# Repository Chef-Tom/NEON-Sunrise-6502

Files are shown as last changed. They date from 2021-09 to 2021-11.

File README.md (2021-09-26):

# NEON-Sunrise-6502
The 6502 based Prototypes

This started in early 2021 as a work from hom distraction and quickly grew into an obsession.
This repository is to work in conjuction with the blog at http://realcheftom.com/6502
and my YouTube documentation of the project at https://www.youtube.com/watch?v=W5MUhNn74IM&list=PLEm9BpY3woKBx9LlBmEiw2NBphkDs04n8

Comments and updates welcome!

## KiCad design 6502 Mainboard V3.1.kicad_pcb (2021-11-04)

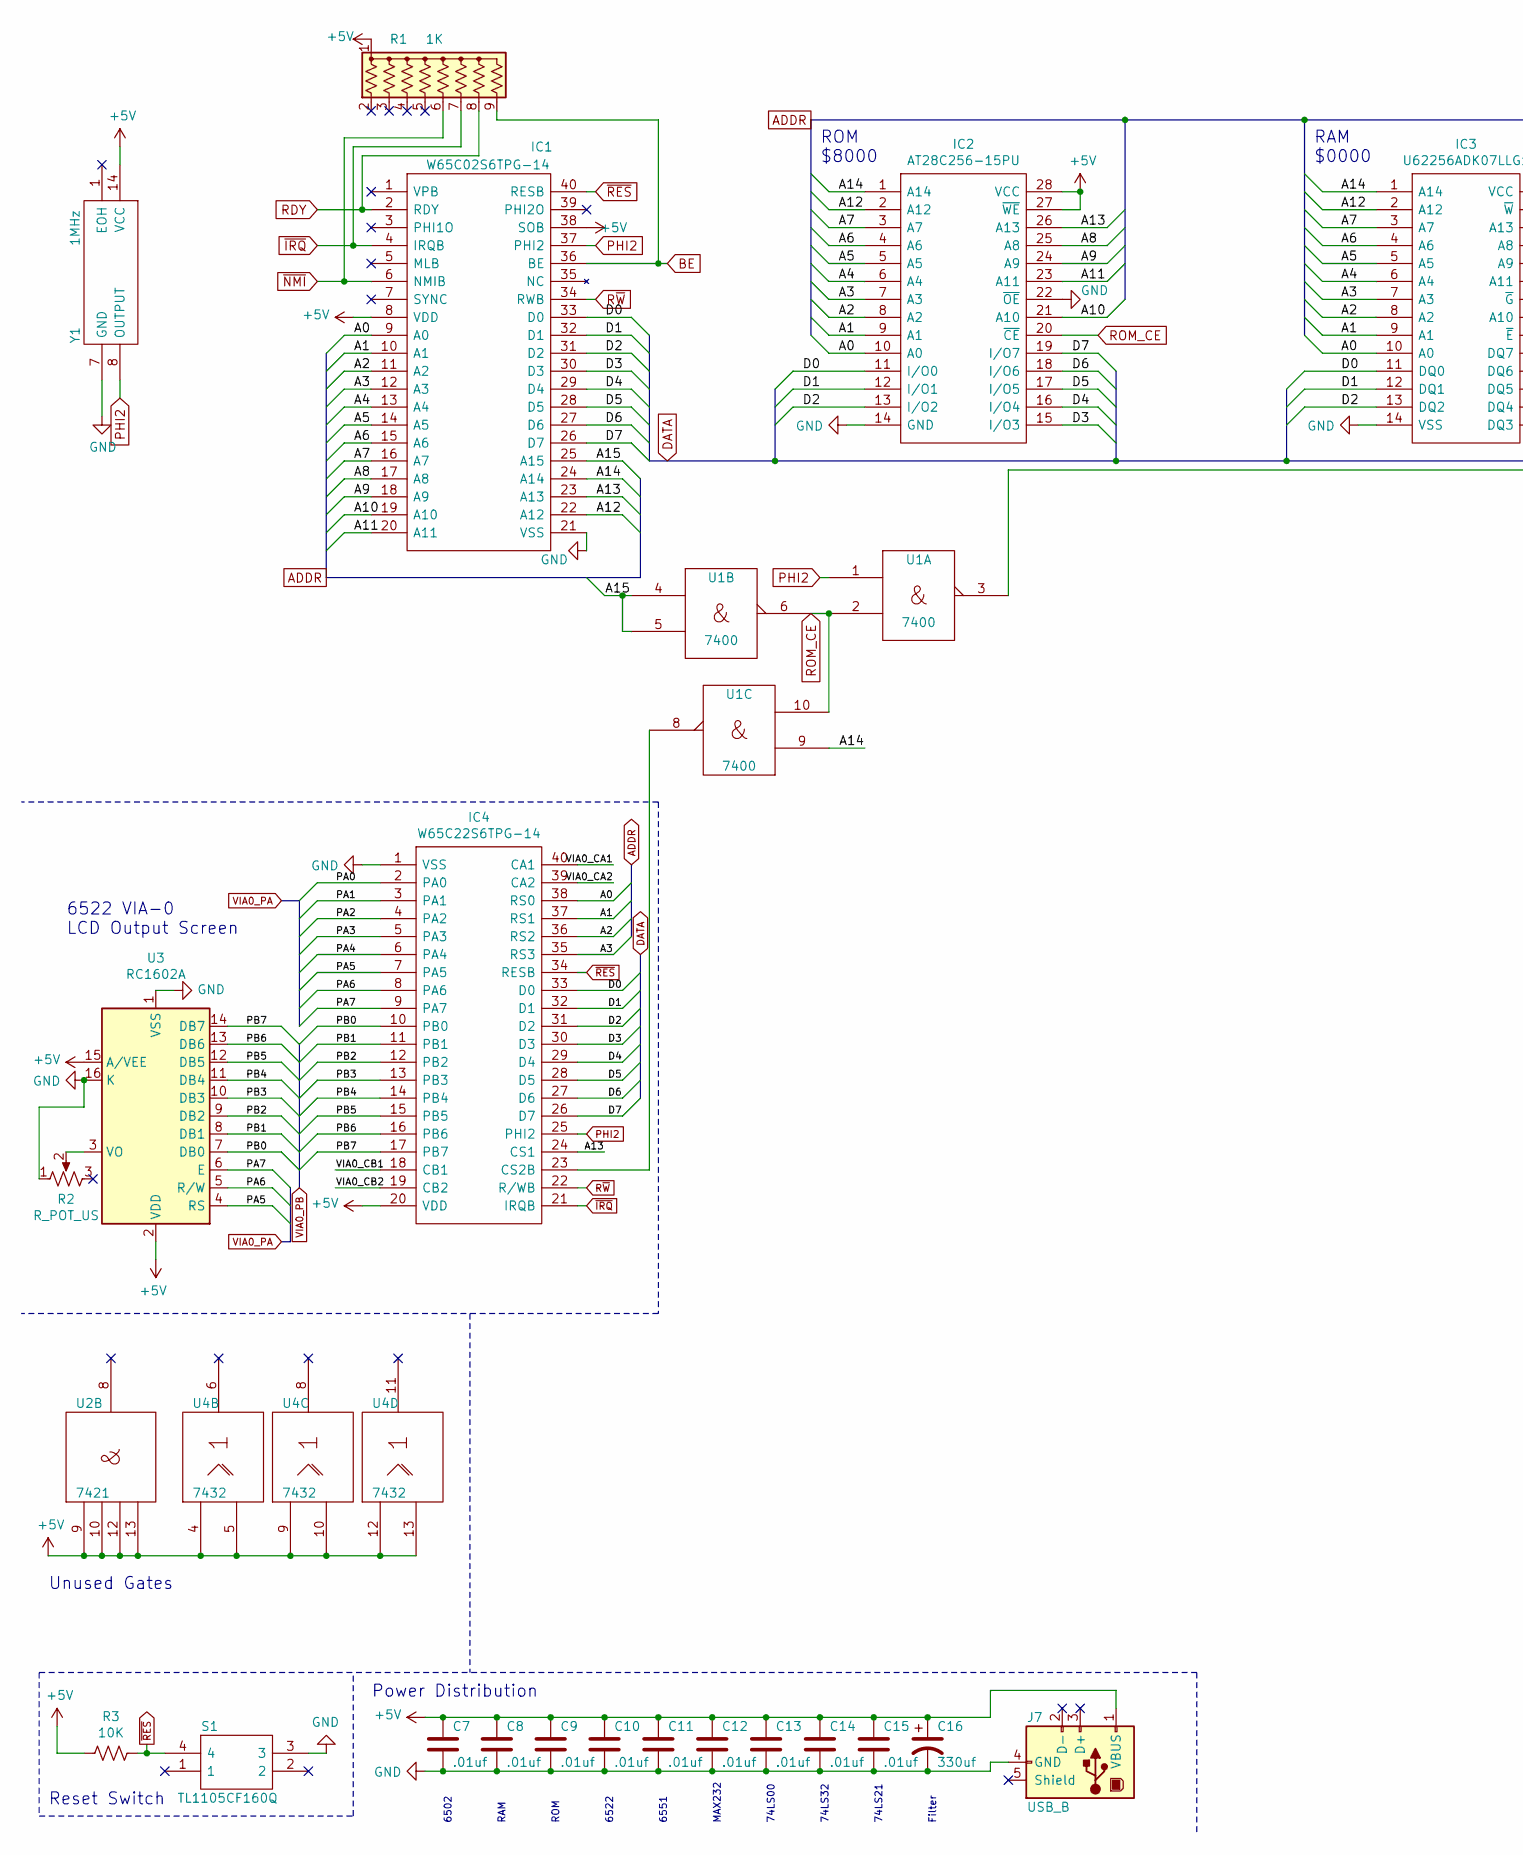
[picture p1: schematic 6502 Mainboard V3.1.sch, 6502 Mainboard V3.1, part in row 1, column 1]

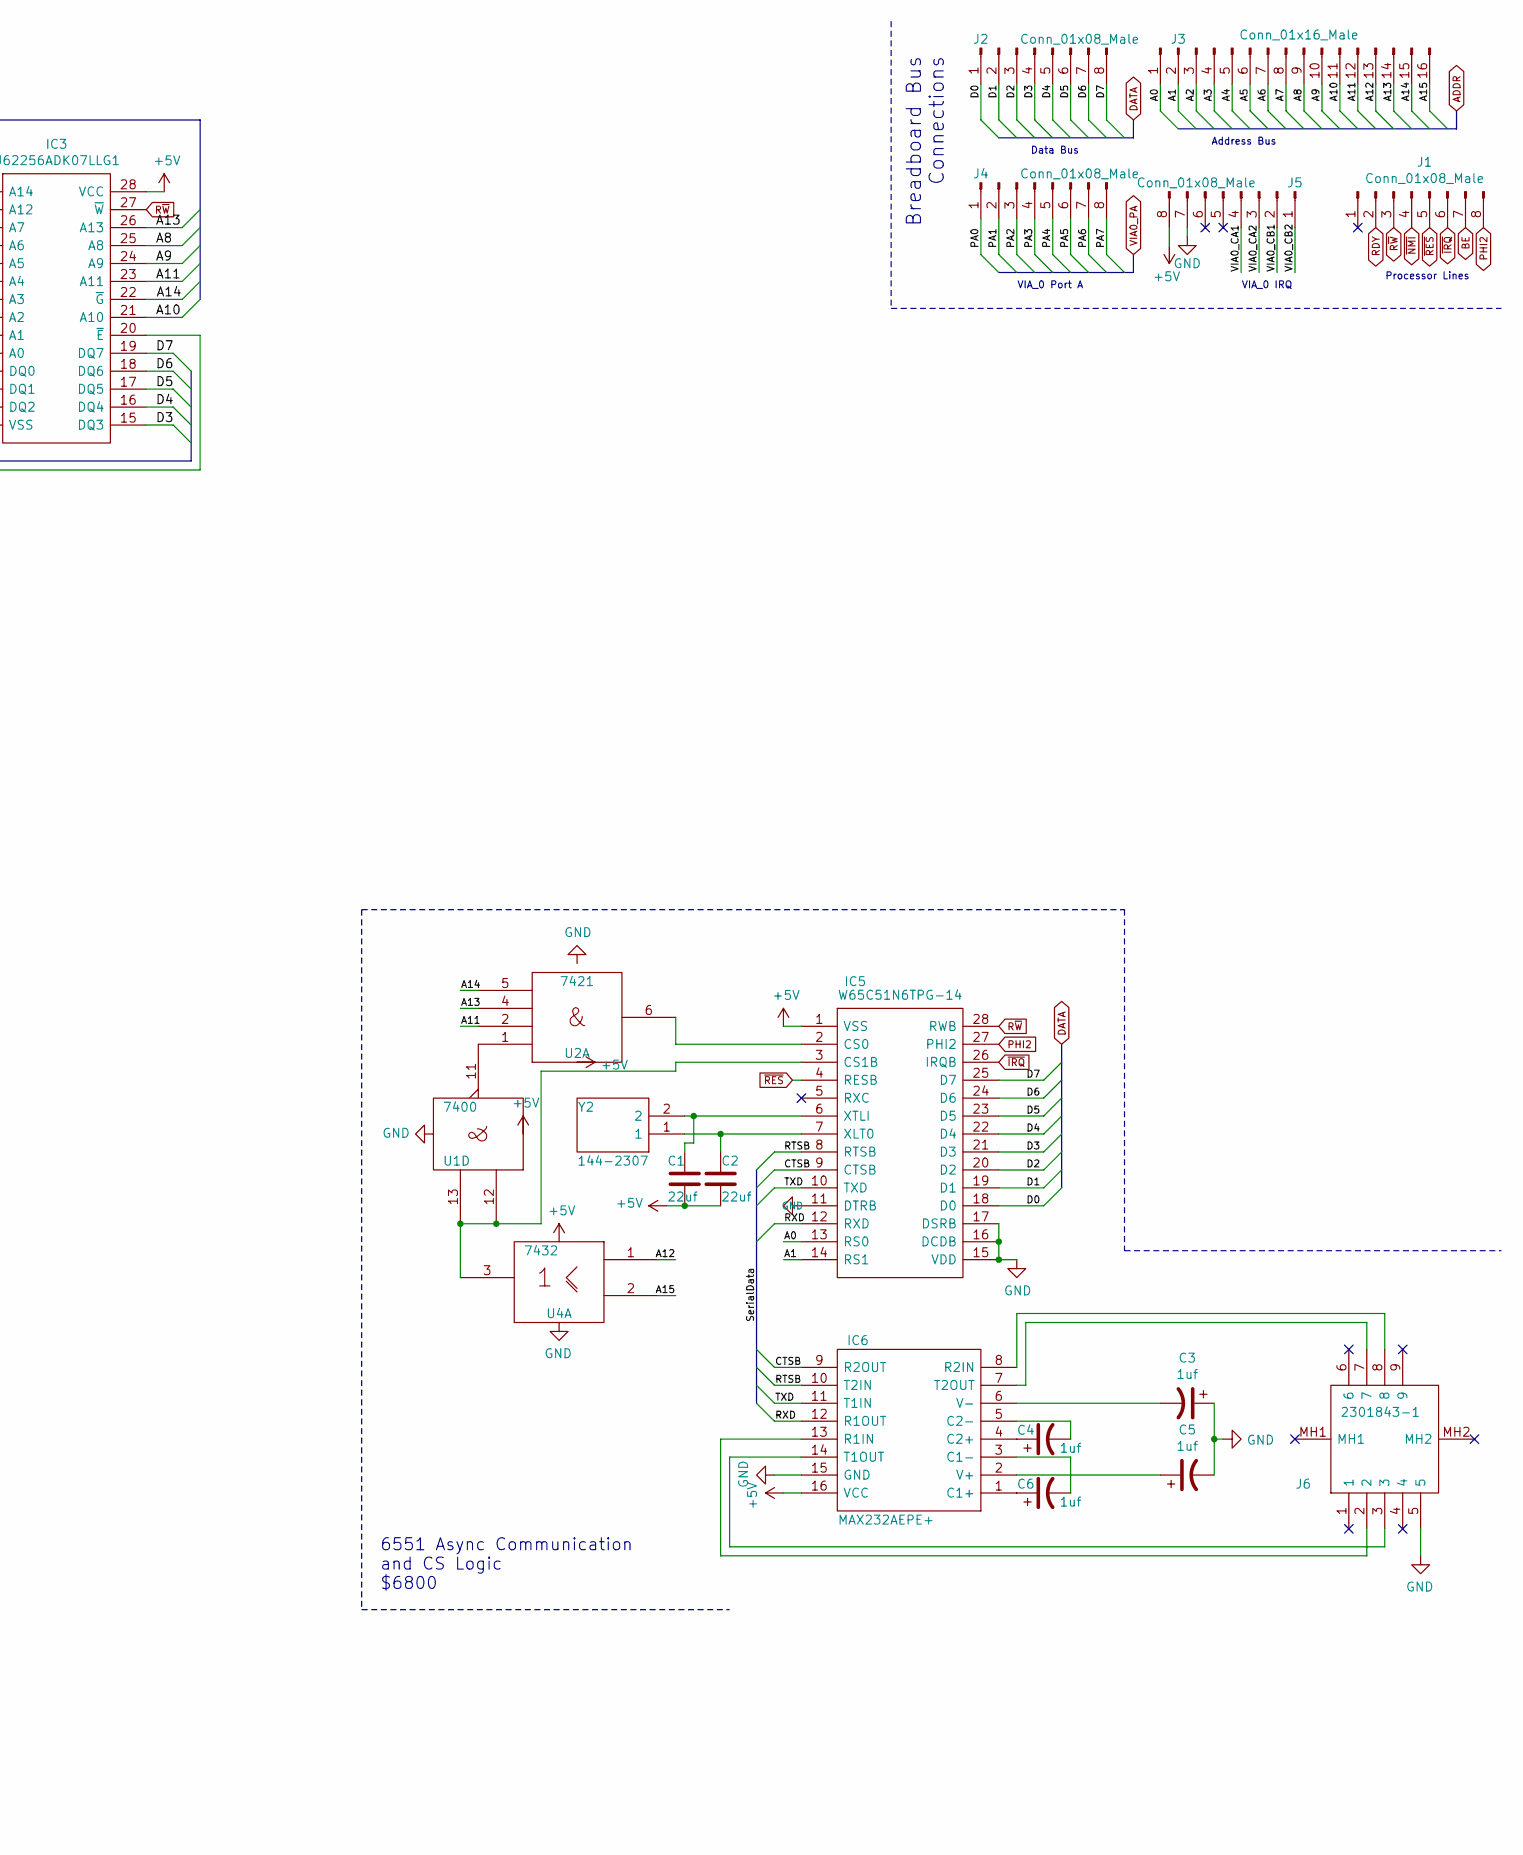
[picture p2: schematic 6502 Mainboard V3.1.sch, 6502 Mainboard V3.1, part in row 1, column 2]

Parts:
C1, C2: 22uf; C_Disc_D3.4mm_W2.1mm_P2.50mm
C3, C4, C5, C6: 1uf; CP_Radial_D5.0mm_P2.50mm
C7, C8, C9, C10, C11, C12, C13, C14, C15: .01uf; C_Disc_D4.3mm_W1.9mm_P5.00mm
C16: 330uf; CP_Radial_D6.3mm_P2.50mm
IC1: W65C02S6TPG-14; DIP-40_W15.24mm_LongPads; Manufacturer_Part_Number W65C02S6TPG-14; Mouser Part Number 955-W65C02S6TPG-14
IC2: AT28C256-15PU; DIP-28_W15.24mm_LongPads; Manufacturer_Part_Number AT28C256-15PU; Mouser Part Number 556-AT28C25615PU
IC3: U62256ADK07LLG1; DIP-28_W15.24mm_LongPads; Manufacturer_Part_Number U62256ADK07LLG1; Mouser Part Number 913-U62256ADK07LLG1
IC4: W65C22S6TPG-14; DIP-40_W15.24mm_LongPads; Manufacturer_Part_Number W65C22S6TPG-14; Mouser Part Number 955-W65C22S6TPG-14
IC5: W65C51N6TPG-14; DIP-28_W15.24mm_LongPads; Manufacturer_Part_Number W65C51N6TPG-14; Mouser Part Number 955-W65C51N6TPG-14
IC6: MAX232AEPE+; DIP-16_W7.62mm_LongPads; Manufacturer_Part_Number MAX232AEPE+; Mouser Part Number 700-MAX232AEPE
J1, J2, J4, J5: Conn_01x08_Male; PinHeader_1x08_P2.54mm_Vertical
J3: Conn_01x16_Male; PinHeader_1x16_P2.54mm_Vertical
J6: 2301843-1; 23018431; Manufacturer_Part_Number 2301843-1; Mouser Part Number 571-2301843-1
J7: USB_B; USB_B_Lumberg_2411_02_Horizontal
R1: 1K; R_Array_SIP9
R2: R_POT_US; Potentiometer_Vishay_T73YP_Vertical
R3: 10K; R_Axial_DIN0411_L9.9mm_D3.6mm_P15.24mm_Horizontal
S1: TL1105CF160Q; Manufacturer_Part_Number TL1105CF160Q; Mouser Part Number 612-TL1105C
U1: 7400; DIP-14_W7.62mm_LongPads
U2: 7421; DIP-14_W7.62mm_LongPads
U3: RC1602A; WC1602A
U4: 7432; DIP-14_W7.62mm_LongPads
Y1: 1MHz; MXO45T2C1M0000; Manufacturer_Part_Number MXO45T-2C-1M0000; Mouser Part Number 774-MXO45T-2C-1M0000
Y2: 144-2307; Crystal_HC52-6mm_Vertical; Manufacturer_Part_Number 144-2307

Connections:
+5V: C1.2, C2.2, C7.1, C8.1, C9.1, C10.1, C11.1, C12.1, C13.1, C14.1, C15.1, C16.1, IC1.8 (VDD), IC1.38 (SOB), IC2.27 (~WE), IC2.28 (VCC), IC3.28 (VCC), IC4.20 (VDD), IC5.1 (VSS), IC6.16 (VCC), J5.8, J7.1 (VBUS), R1.1 (common), R3.2, U1.14 (Vcc), U2.9, U2.10, U2.12, U2.13, U2.14 (Vcc), U3.2 (VDD), U3.15 (A/VEE), U4.4, U4.5, U4.9, U4.10, U4.12, U4.13, U4.14 (Vcc), Y1.14 (VCC)
/A0: IC1.9 (A0), IC2.10 (A0), IC3.10 (A0), IC4.38 (RS0), IC5.13 (RS0), J3.1
/A1: IC1.10 (A1), IC2.9 (A1), IC3.9 (A1), IC4.37 (RS1), IC5.14 (RS1), J3.2
/A2: IC1.11 (A2), IC2.8 (A2), IC3.8 (A2), IC4.36 (RS2), J3.3
/A3: IC1.12 (A3), IC2.7 (A3), IC3.7 (A3), IC4.35 (RS3), J3.4
/A4: IC1.13 (A4), IC2.6 (A4), IC3.6 (A4), J3.5
/A5: IC1.14 (A5), IC2.5 (A5), IC3.5 (A5), J3.6
/A6: IC1.15 (A6), IC2.4 (A6), IC3.4 (A6), J3.7
/A7: IC1.16 (A7), IC2.3 (A7), IC3.3 (A7), J3.8
/A8: IC1.17 (A8), IC2.25 (A8), IC3.25 (A8), J3.9
/A9: IC1.18 (A9), IC2.24 (A9), IC3.24 (A9), J3.10
/A10: IC1.19 (A10), IC2.21 (A10), IC3.21 (A10), J3.11
/A11: IC1.20 (A11), IC2.23 (A11), IC3.23 (A11), J3.12, U2.2
/A12: IC1.22 (A12), IC2.2 (A12), IC3.2 (A12), J3.13, U4.1
/A13: IC1.23 (A13), IC2.26 (A13), IC3.26 (A13), IC4.24 (CS1), J3.14, U2.4
/A14: IC1.24 (A14), IC2.1 (A14), IC3.1 (A14), IC3.22 (~G), J3.15, U1.9, U2.5
/A15: IC1.25 (A15), J3.16, U1.4, U1.5, U4.2
/CTSB: IC5.9 (CTSB), IC6.9 (R2OUT)
/D0: IC1.33 (D0), IC2.11 (I/O0), IC3.11 (DQ0), IC4.33 (D0), IC5.18 (D0), J2.1
/D1: IC1.32 (D1), IC2.12 (I/O1), IC3.12 (DQ1), IC4.32 (D1), IC5.19 (D1), J2.2
/D2: IC1.31 (D2), IC2.13 (I/O2), IC3.13 (DQ2), IC4.31 (D2), IC5.20 (D2), J2.3
/D3: IC1.30 (D3), IC2.15 (I/O3), IC3.15 (DQ3), IC4.30 (D3), IC5.21 (D3), J2.4
/D4: IC1.29 (D4), IC2.16 (I/O4), IC3.16 (DQ4), IC4.29 (D4), IC5.22 (D4), J2.5
/D5: IC1.28 (D5), IC2.17 (I/O5), IC3.17 (DQ5), IC4.28 (D5), IC5.23 (D5), J2.6
/D6: IC1.27 (D6), IC2.18 (I/O6), IC3.18 (DQ6), IC4.27 (D6), IC5.24 (D6), J2.7
/D7: IC1.26 (D7), IC2.19 (I/O7), IC3.19 (DQ7), IC4.26 (D7), IC5.25 (D7), J2.8
/PA0: IC4.2 (PA0), J4.1
/PA1: IC4.3 (PA1), J4.2
/PA2: IC4.4 (PA2), J4.3
/PA3: IC4.5 (PA3), J4.4
/PA4: IC4.6 (PA4), J4.5
/PA5: IC4.7 (PA5), J4.6, U3.4 (RS)
/PA6: IC4.8 (PA6), J4.7, U3.5 (R/W)
/PA7: IC4.9 (PA7), J4.8, U3.6 (E)
/PB0: IC4.10 (PB0), U3.7 (DB0)
/PB1: IC4.11 (PB1), U3.8 (DB1)
/PB2: IC4.12 (PB2), U3.9 (DB2)
/PB3: IC4.13 (PB3), U3.10 (DB3)
/PB4: IC4.14 (PB4), U3.11 (DB4)
/PB5: IC4.15 (PB5), U3.12 (DB5)
/PB6: IC4.16 (PB6), U3.13 (DB6)
/PB7: IC4.17 (PB7), U3.14 (DB7)
/RTSB: IC5.8 (RTSB), IC6.10 (T2IN)
/RXD: IC5.12 (RXD), IC6.12 (R1OUT)
/TXD: IC5.10 (TXD), IC6.11 (T1IN)
/VIA0_CA1: IC4.40 (CA1), J5.4
/VIA0_CA2: IC4.39 (CA2), J5.3
/VIA0_CB1: IC4.18 (CB1), J5.2
/VIA0_CB2: IC4.19 (CB2), J5.1
BE: IC1.36 (BE), J1.7, R1.9 (R8)
GND: C3.1, C5.2, C7.2, C8.2, C9.2, C10.2, C11.2, C12.2, C13.2, C14.2, C15.2, C16.2, IC1.21 (VSS), IC2.14 (GND), IC2.22 (~OE), IC3.14 (VSS), IC4.1 (VSS), IC5.11 (DTRB), IC5.15 (VDD), IC5.16 (DCDB), IC5.17 (DSRB), IC6.15 (GND), J5.7, J6.5, J7.4 (GND), R2.1, S1.3, U1.7 (GND), U2.7 (Gnd), U3.1 (VSS), U3.16 (K), U4.7 (Gnd), Y1.7 (GND)
unnamed: C1.1, IC5.6 (XTLI), Y2.2
unnamed: C2.1, IC5.7 (XLT0), Y2.1
unnamed: C3.2, IC6.6 (V-)
unnamed: C4.1, IC6.4 (C2+)
unnamed: C4.2, IC6.5 (C2-)
unnamed: C5.1, IC6.2 (V+)
unnamed: C6.1, IC6.1 (C1+)
unnamed: C6.2, IC6.3 (C1-)
unnamed: IC3.20 (~E), U1.3
unnamed: IC4.23 (CS2B), U1.8
unnamed: IC5.2 (CS0), U2.6
unnamed: IC5.3 (CS1B), U1.12, U1.13, U4.3
unnamed: IC6.7 (T2OUT), J6.7
unnamed: IC6.8 (R2IN), J6.8
unnamed: IC6.13 (R1IN), J6.2
unnamed: IC6.14 (T1OUT), J6.3
unnamed: R2.2, U3.3 (VO)
unnamed: U1.11, U2.1
PHI2: IC1.37 (PHI2), IC4.25 (PHI2), IC5.27 (PHI2), J1.8, U1.1, Y1.8 (OUTPUT)
RDY: IC1.2 (RDY), J1.2, R1.8 (R7)
ROM_CE: IC2.20 (~CE), U1.2, U1.6, U1.10
R~W: IC1.34 (RWB), IC3.27 (~W), IC4.22 (R/WB), IC5.28 (RWB), J1.3
~IRQ: IC1.4 (IRQB), IC4.21 (IRQB), IC5.26 (IRQB), J1.6, R1.7 (R6)
~NMI: IC1.6 (NMIB), J1.4, R1.6 (R5)
~RES: IC1.40 (RESB), IC4.34 (RESB), IC5.4 (RESB), J1.5, R3.1, S1.4

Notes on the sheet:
Reset Switch
6551 Async Communication and CS Logic $6800
ROM $8000
RAM $0000
6522 VIA-0 LCD Output Screen
6502
RAM
ROM
6522
6551
MAX232
74LS00
74LS32
74LS21
Filter
Power Distribution
Unused Gates
VIA_0 IRQ
VIA_0 Port A
Processor Lines
Address Bus
Data Bus
Breadboard Bus Connections

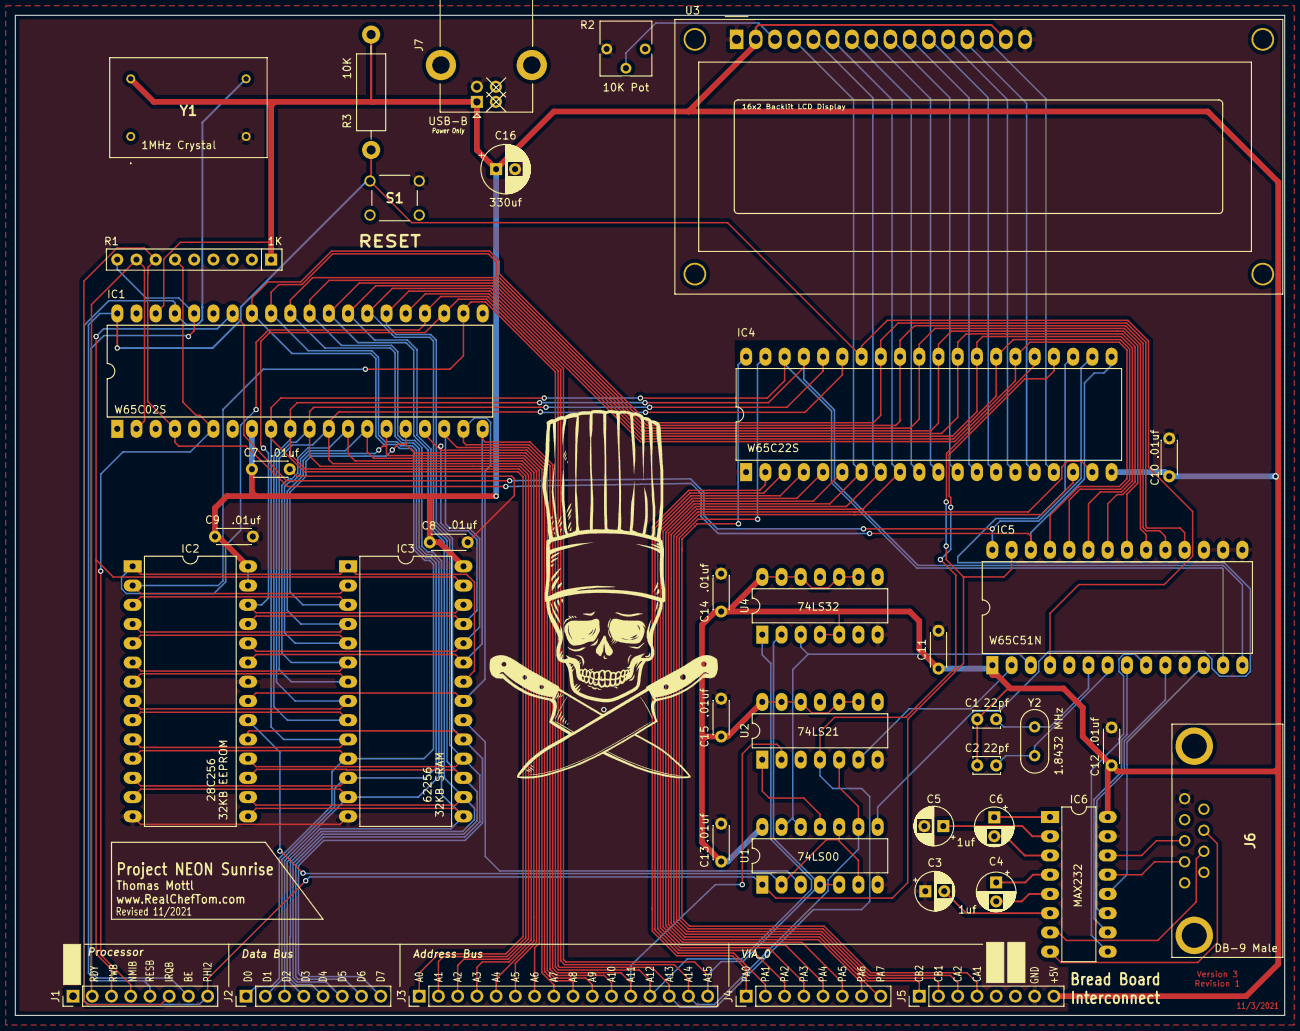
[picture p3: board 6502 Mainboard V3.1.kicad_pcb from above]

Board: 2 copper layers, 167.6 x 132.1 mm, 39 parts (0 on the bottom side), 76 nets.

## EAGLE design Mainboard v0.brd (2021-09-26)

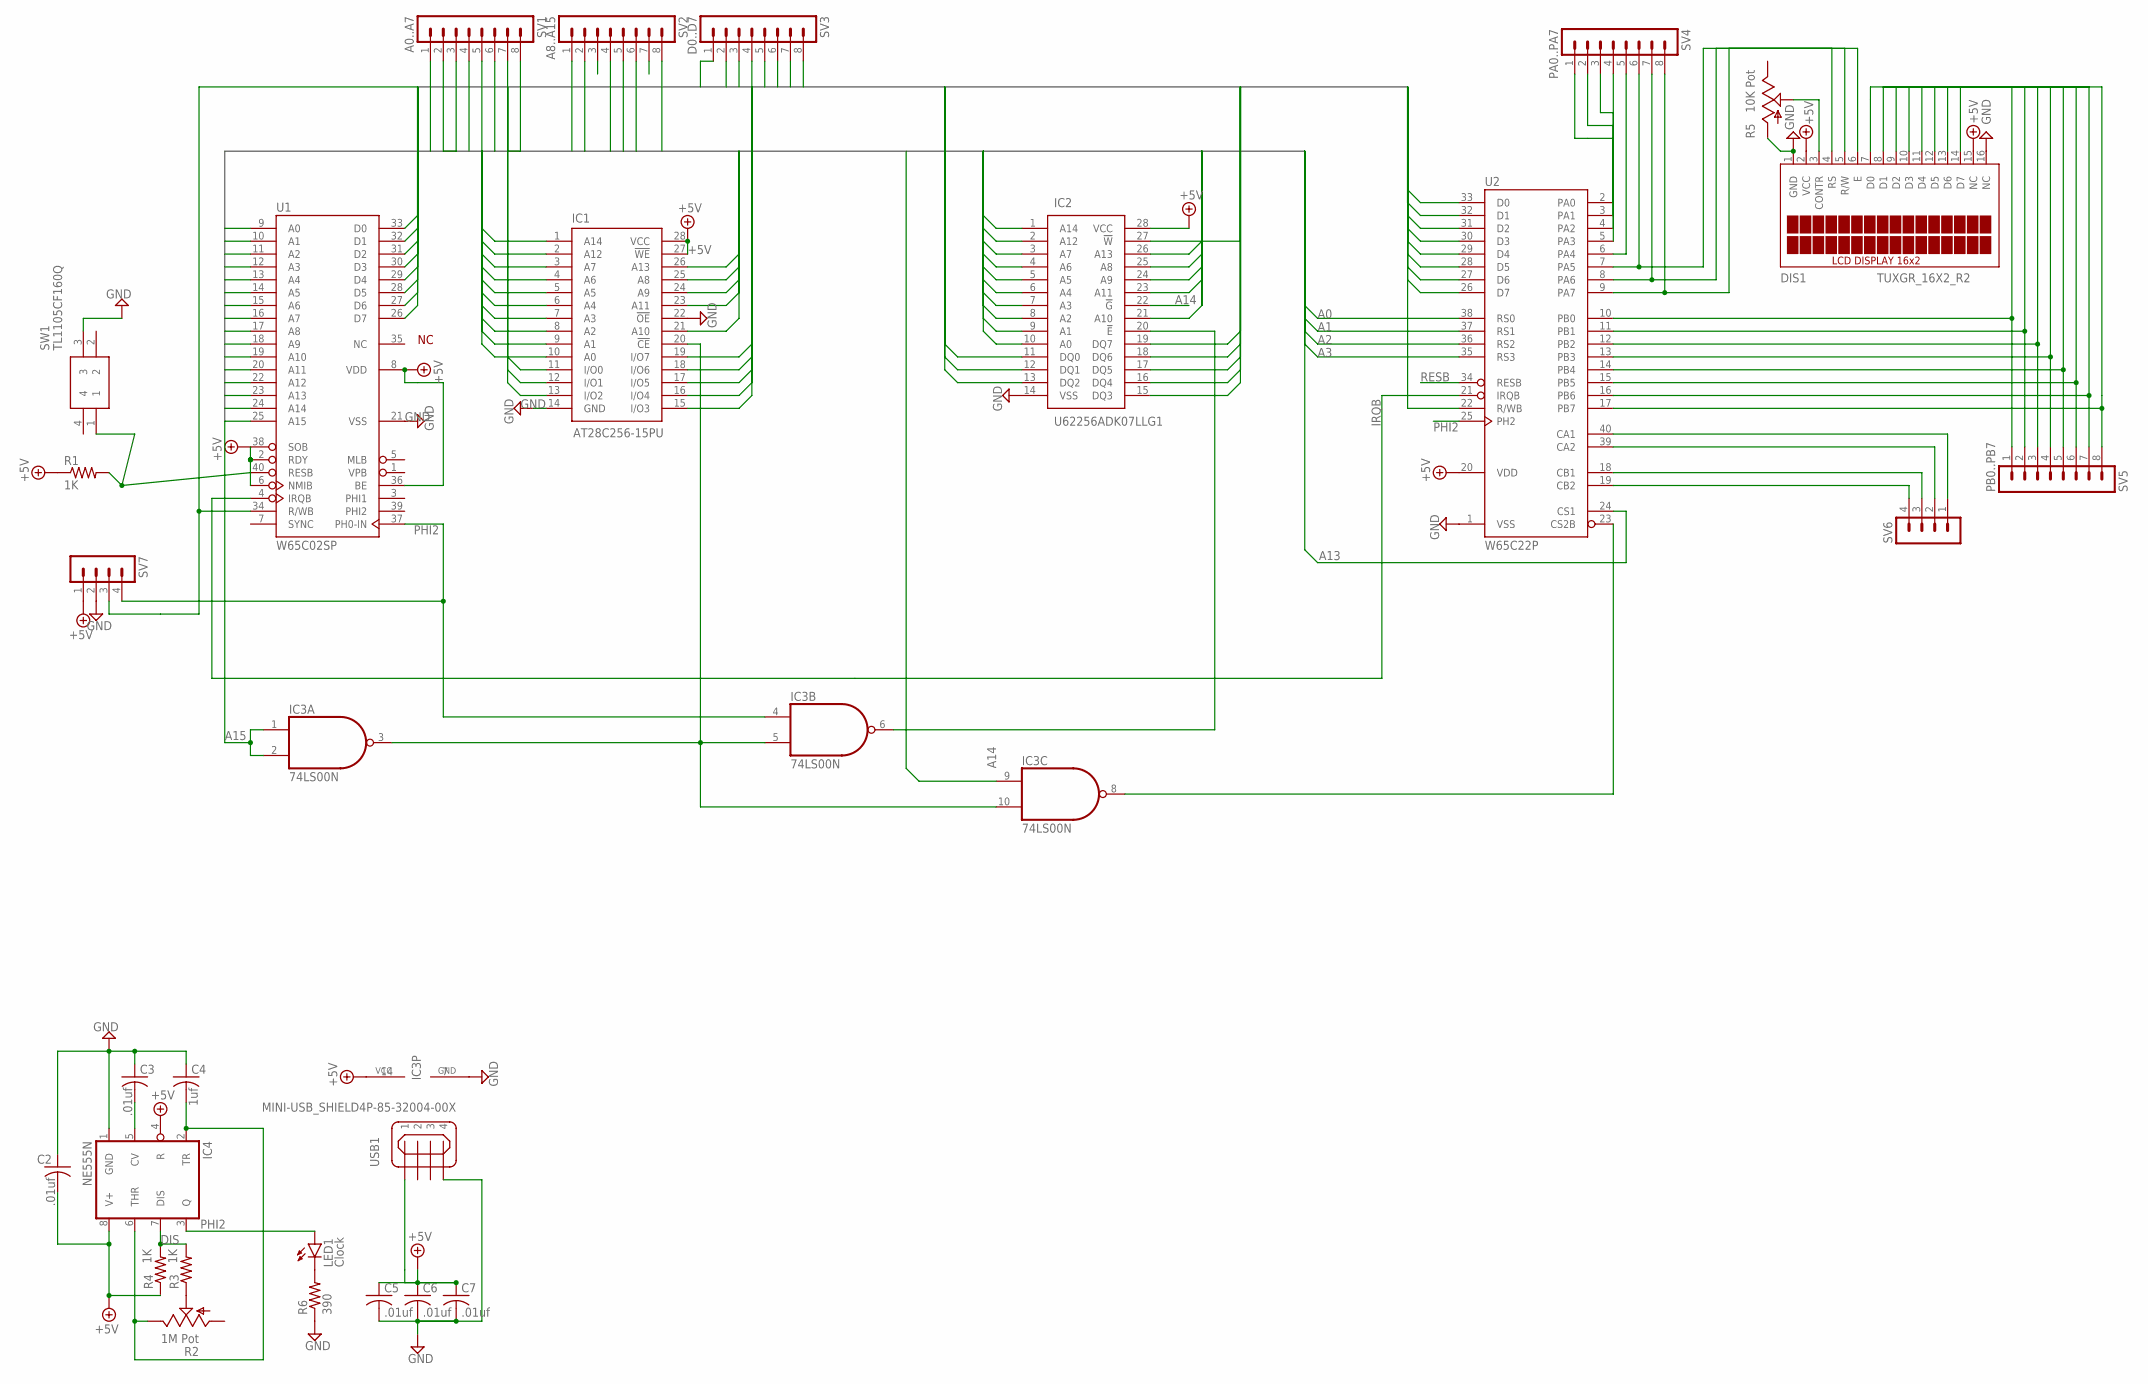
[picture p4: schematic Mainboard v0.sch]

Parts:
C2, C3, C5, C6, C7: .01uf; C075-032X103
C4: 1uf; C075-032X103
DIS1: TUXGR_16X2_R2
IC1: AT28C256-15PU; DIP1556W56P254L3702H483Q28N
IC2: U62256ADK07LLG1; DIP1524W59P254L3710H510Q28N
IC3: 74LS00N; DIL14
IC4: NE555N; DIL08
LED1: Clock; LED5MM
R1, R3, R4: 1K; 0204/7
R2: 1M Pot; B25U
R5: 10K Pot; B25U
R6: 390; 0204/7
SV1: A0..A7; MA08-1
SV2: A8..A15; MA08-1
SV3: D0..D7; MA08-1
SV4: PA0..PA7; MA08-1
SV5: PB0..PB7; MA08-1
SV6, SV7: MA04-1
SW1: TL1105CF160Q
U1: W65C02SP; DIP-40
U2: W65C22P; DIP-40
USB1: MINI-USB_SHIELD4P-85-32004-00X; 85-32004-00X

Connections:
+5V: C2.2, C5.1, C6.1, C7.1, DIS1.2 (VCC), DIS1.15 (NC), IC1.27 (!WE), IC1.28 (VCC), IC2.28 (VCC), IC3.14 (VCC), IC4.4 (R), IC4.8 (V+), R1.1, R4.1, SV7.1, U1.2 (RDY), U1.6 (NMIB), U1.8 (VDD), U1.36 (BE), U1.38 (SOB), U2.20 (VDD), USB1.1
A0: IC1.10 (A0), IC2.10 (A0), SV1.1, U1.9 (A0), U2.38 (RS0)
A1: IC1.9 (A1), IC2.9 (A1), SV1.2, U1.10 (A1), U2.37 (RS1)
A2: IC1.8 (A2), IC2.8 (A2), SV1.3, U1.11 (A2), U2.36 (RS2)
A3: IC1.7 (A3), IC2.7 (A3), SV1.4, U1.12 (A3), U2.35 (RS3)
A4: IC1.6 (A4), IC2.6 (A4), SV1.5, U1.13 (A4)
A5: IC1.5 (A5), IC2.5 (A5), SV1.6, U1.14 (A5)
A6: IC1.4 (A6), IC2.4 (A6), SV1.7, U1.15 (A6)
A7: IC1.3 (A7), IC2.3 (A7), SV1.8, U1.16 (A7)
A8: IC1.25 (A8), IC2.25 (A8), SV2.1, U1.17 (A8)
A9: IC1.24 (A9), IC2.24 (A9), SV2.2, U1.18 (A9)
A10: IC1.21 (A10), IC2.21 (A10), SV2.3, U1.19 (A10)
A11: IC1.23 (A11), IC2.23 (A11), SV2.4, U1.20 (A11)
A12: IC1.2 (A12), IC2.2 (A12), SV2.5, U1.22 (A12)
A13: IC1.26 (A13), IC2.26 (A13), SV2.6, U1.23 (A13), U2.24 (CS1)
A14: IC1.1 (A14), IC2.1 (A14), IC2.22 (!G), IC3.9 (I0), SV2.7, U1.24 (A14)
A15: IC3.1 (I0), IC3.2 (I1), SV2.8, U1.25 (A15)
CLK-1: C4.2, IC4.2 (TR), IC4.6 (THR), R2.E
D0: IC1.11 (I/O0), IC2.11 (DQ0), SV3.1, U1.33 (D0), U2.33 (D0)
D1: IC1.12 (I/O1), IC2.12 (DQ1), SV3.2, U1.32 (D1), U2.32 (D1)
D2: IC1.13 (I/O2), IC2.13 (DQ2), SV3.3, U1.31 (D2), U2.31 (D2)
D3: IC1.15 (I/O3), IC2.15 (DQ3), SV3.4, U1.30 (D3), U2.30 (D3)
D4: IC1.16 (I/O4), IC2.16 (DQ4), U1.29 (D4), U2.29 (D4)
D5: IC1.17 (I/O5), IC2.17 (DQ5), SV3.5, SV3.6, U1.28 (D5), U2.28 (D5)
D6: IC1.18 (I/O6), IC2.18 (DQ6), SV3.7, U1.27 (D6), U2.27 (D6)
D7: IC1.19 (I/O7), IC2.19 (DQ7), SV3.8, U1.26 (D7), U2.26 (D7)
DIS: IC4.7 (DIS), R3.2, R4.2
GND: C2.1, C3.1, C4.1, C5.2, C6.2, C7.2, DIS1.1 (GND), DIS1.16 (NC), IC1.14 (GND), IC1.22 (!OE), IC2.14 (VSS), IC3.7 (GND), IC4.1 (GND), R5.A, R6.1, SV7.2, SW1.3, U1.21 (VSS), U2.1 (VSS), USB1.4
IRQB: U1.4 (IRQB), U2.21 (IRQB)
unnamed: IC1.20 (!CE), IC3.3 (O), IC3.5 (I1), IC3.10 (I1)
unnamed: IC3.8 (O), U2.23 (CS2B)
unnamed: R2.S, R3.1
unnamed: C3.2, IC4.5 (CV)
unnamed: LED1.K (C), R6.2
unnamed: IC2.20 (!E), IC3.6 (O)
unnamed: DIS1.3 (CONTR), R5.S
unnamed: DIS1.7 (D0), SV5.1, U2.10 (PB0)
unnamed: DIS1.8 (D1), SV5.2, U2.11 (PB1)
unnamed: DIS1.9 (D2), SV5.3, U2.12 (PB2)
unnamed: DIS1.10 (D3), SV5.4, U2.13 (PB3)
unnamed: DIS1.11 (D4), SV5.5, U2.14 (PB4)
unnamed: DIS1.12 (D5), SV5.6, U2.15 (PB5)
unnamed: DIS1.13 (D6), SV5.7, U2.16 (PB6)
unnamed: DIS1.14 (D7), SV5.8, U2.17 (PB7)
unnamed: DIS1.6 (E), SV4.8, U2.9 (PA7)
unnamed: DIS1.5 (R/W), SV4.7, U2.8 (PA6)
unnamed: DIS1.4 (RS), SV4.6, U2.7 (PA5)
unnamed: SV4.1, U2.2 (PA0)
unnamed: SV4.2, U2.3 (PA1)
unnamed: SV4.3, U2.4 (PA2)
unnamed: SV4.4, U2.5 (PA3)
unnamed: SV4.5, U2.6 (PA4)
unnamed: SV6.1, U2.40 (CA1)
unnamed: SV6.2, U2.39 (CA2)
unnamed: SV6.3, U2.18 (CB1)
unnamed: SV6.4, U2.19 (CB2)
PHI2: IC3.4 (I0), IC4.3 (Q), LED1.A, SV7.4, U1.37 (PH0-IN), U2.25 (PH2)
RESB: R1.2, SW1.1, U1.40 (RESB), U2.34 (RESB)
RWB: IC2.27 (!W), SV7.3, U1.34 (R/WB), U2.22 (R/WB)

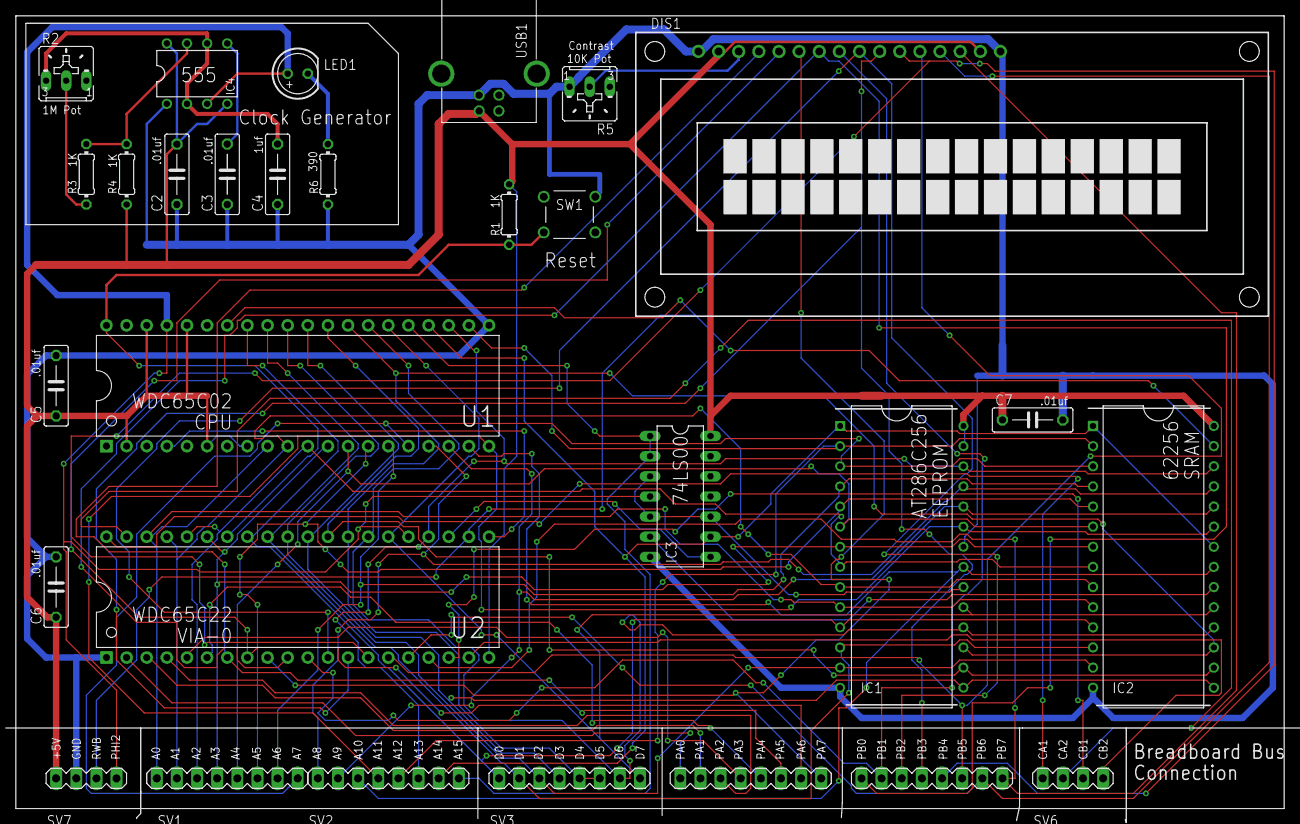
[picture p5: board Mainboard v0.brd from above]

Board: 2 copper layers, 160.0 x 100.0 mm, 29 parts (0 on the bottom side), 59 nets.

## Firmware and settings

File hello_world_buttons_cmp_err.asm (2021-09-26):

PORTB = $6000
PORTA = $6001
DDRB = $6002
DDRA = $6003
PCR = $600c
IFR = $600d
IER = $600e

MSG = $1000 	; Message to Display, 80bytes


E  = %10000000
RW = %01000000
RS = %00100000



	.org $8000
reset:				; ---   Initialize the System   ---
	SEI				;Set Interrupt Disable Flag
	LDX #$FF
	TXS				; Initialize stack pointer to $01FF
	
	LDA #$00
	STA MSG			; Set the default message to null
	STA PCR			; Set CA1, CA2, CB1, CB2 to Negetive Active Edge (%00000000)
	STA $01			; Store Zero at ZP01 (used in IRQ)
	LDA #%10000010
	STA IER			; Enable Interrupts on CA1
	

					; ---   Initialize the Display   ---
	LDA #%11111111	; Set all pins on port B as outupt
	STA DDRB
	LDA #%11100000  ; Set top 3 bits on port A as output, botom 5 as input
	STA DDRA
	LDA #%00111000	; Set 8-bit mode, 2 line display, 5x8 font
	JSR lcd_instruction
	LDA #%00001110	; Set Display On, Cursor On, Blink Off
	JSR lcd_instruction
	LDA #%00000110	; Set Increment Counter (right), Shift Off
	JSR lcd_instruction
	LDA #%00000001  ; Clear Screen
	JSR lcd_instruction
	CLI				; Clear Interrupt Disable Bit	
	
loop:
	LDA #%00000010  ; Set cursor to Home
	JSR lcd_instruction		
	LDX #0
print:
	LDY $01
	LDA MSG,x
	BEQ loop
	JSR print_char
	INX
	JMP print

	

	;.org $9000
lcd_instruction:
	SEI
	JSR lcd_wait
	STA PORTB		; Send data to PORTB
	LDA #0			; Clear RS/RW/Enable
	STA PORTA
	LDA #E	; 		; Leave Set Enable
	STA PORTA
	LDA #0			; Clear RS/RW/Enable
	STA PORTA
	CLI
	RTS

	;.org $A000
print_char:
	SEI
	JSR lcd_wait
	STA PORTB		; Send data to PORTB
	LDA #RS			; Set RS
	STA PORTA
	LDA #(RS | E)	; Leave RS Set, Set Enable
	STA PORTA
	LDA #RS			; Leave RS Set, Clear Enable
	STA PORTA
	CLI
	RTS

	;.org $B000
lcd_wait:
	SEI
	PHA				; Push A to stack to preserve instruction
	LDA #%00000000	; Set PORTB to Input
	STA DDRB
lcd_busy:
	NOP
	LDA #RW			; Set RW Bit
	STA PORTA
	LDA #(RW | E)	; Leave RW Set, Set Enable
	STA PORTA
	lda PORTB
	AND #%10000000	; AND to check for only BUSY FLAG bit
	BNE lcd_busy	; If Busy Flag is set, loop.

	LDA #RW			; Set RW Bit (Cleares Enable)
	STA PORTA
	LDA #%11111111	; Reset PORTB to Output
	STA DDRB
	PLA				; Pull A back from stack.
	CLI
	RTS

	.org $C000
irqb:
	PHA				; Push A on Stack
	TXA
	PHA				; Push X on Stack
	
	LDX #$00
	LDA PORTA
	STA $01
	AND #%00000001	
	beq MessageA
	AND #%00000010
	beq MessageB
	AND #%0000100
	beq MessageC
	AND #%00001000
	beq MessageD
	LDA $01			; No valid options, load what was read out of Port A
	ADC #$30		; Add 0x30 to it to make it start at 0 in teh ASCII Chart
	STA MSG,x		; Store that as the first char of the error
	INX
MessageError:		;  Return to Null in case of an Error
	LDA msg_e,x
	STA MSG,x
	BEQ IRQ_done
	INX
	JMP MessageError
MessageA:
	LDA msg_a,x
	STA MSG,x
	BEQ IRQ_done
	INX
	JMP MessageA
MessageB:
	LDA msg_b,x
	STA MSG,x
	BEQ IRQ_done
	INX
	JMP MessageB
MessageC:
	LDA msg_c,x
	STA MSG,x
	BEQ IRQ_done
	INX
	JMP MessageC
MessageD:
	LDA msg_d,x
	STA MSG,x
	BEQ IRQ_done
	INX
	JMP MessageD
IRQ_done:	 
	PLA				; Pull X from Stack
	TAX
	PLA				; Pull A from Stack
	RTI

;   ---   End of Program, Start of Static Data   ---	

	.org $fe00
msg_a:	.asciiz "Button 1"
msg_b:	.asciiz "Button 2"
msg_c:	.asciiz "Button 3"
msg_d:	.asciiz "Button 4"
msg_e:	.asciiz "  Error."

	.org $fffa
	.word irqb
	.word reset
	.word irqb
	
